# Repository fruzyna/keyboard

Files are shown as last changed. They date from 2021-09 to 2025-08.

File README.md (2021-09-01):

# keyboard

Here I will put my keyboard development. I will attempt to tag each version I get printed. For the first version I used these libraries:
- https://github.com/keebio/keebio-components
- https://github.com/keebio/Keebio-Parts.pretty
- https://github.com/daprice/keyswitches.pretty

I then modded them to my liking for future versions.

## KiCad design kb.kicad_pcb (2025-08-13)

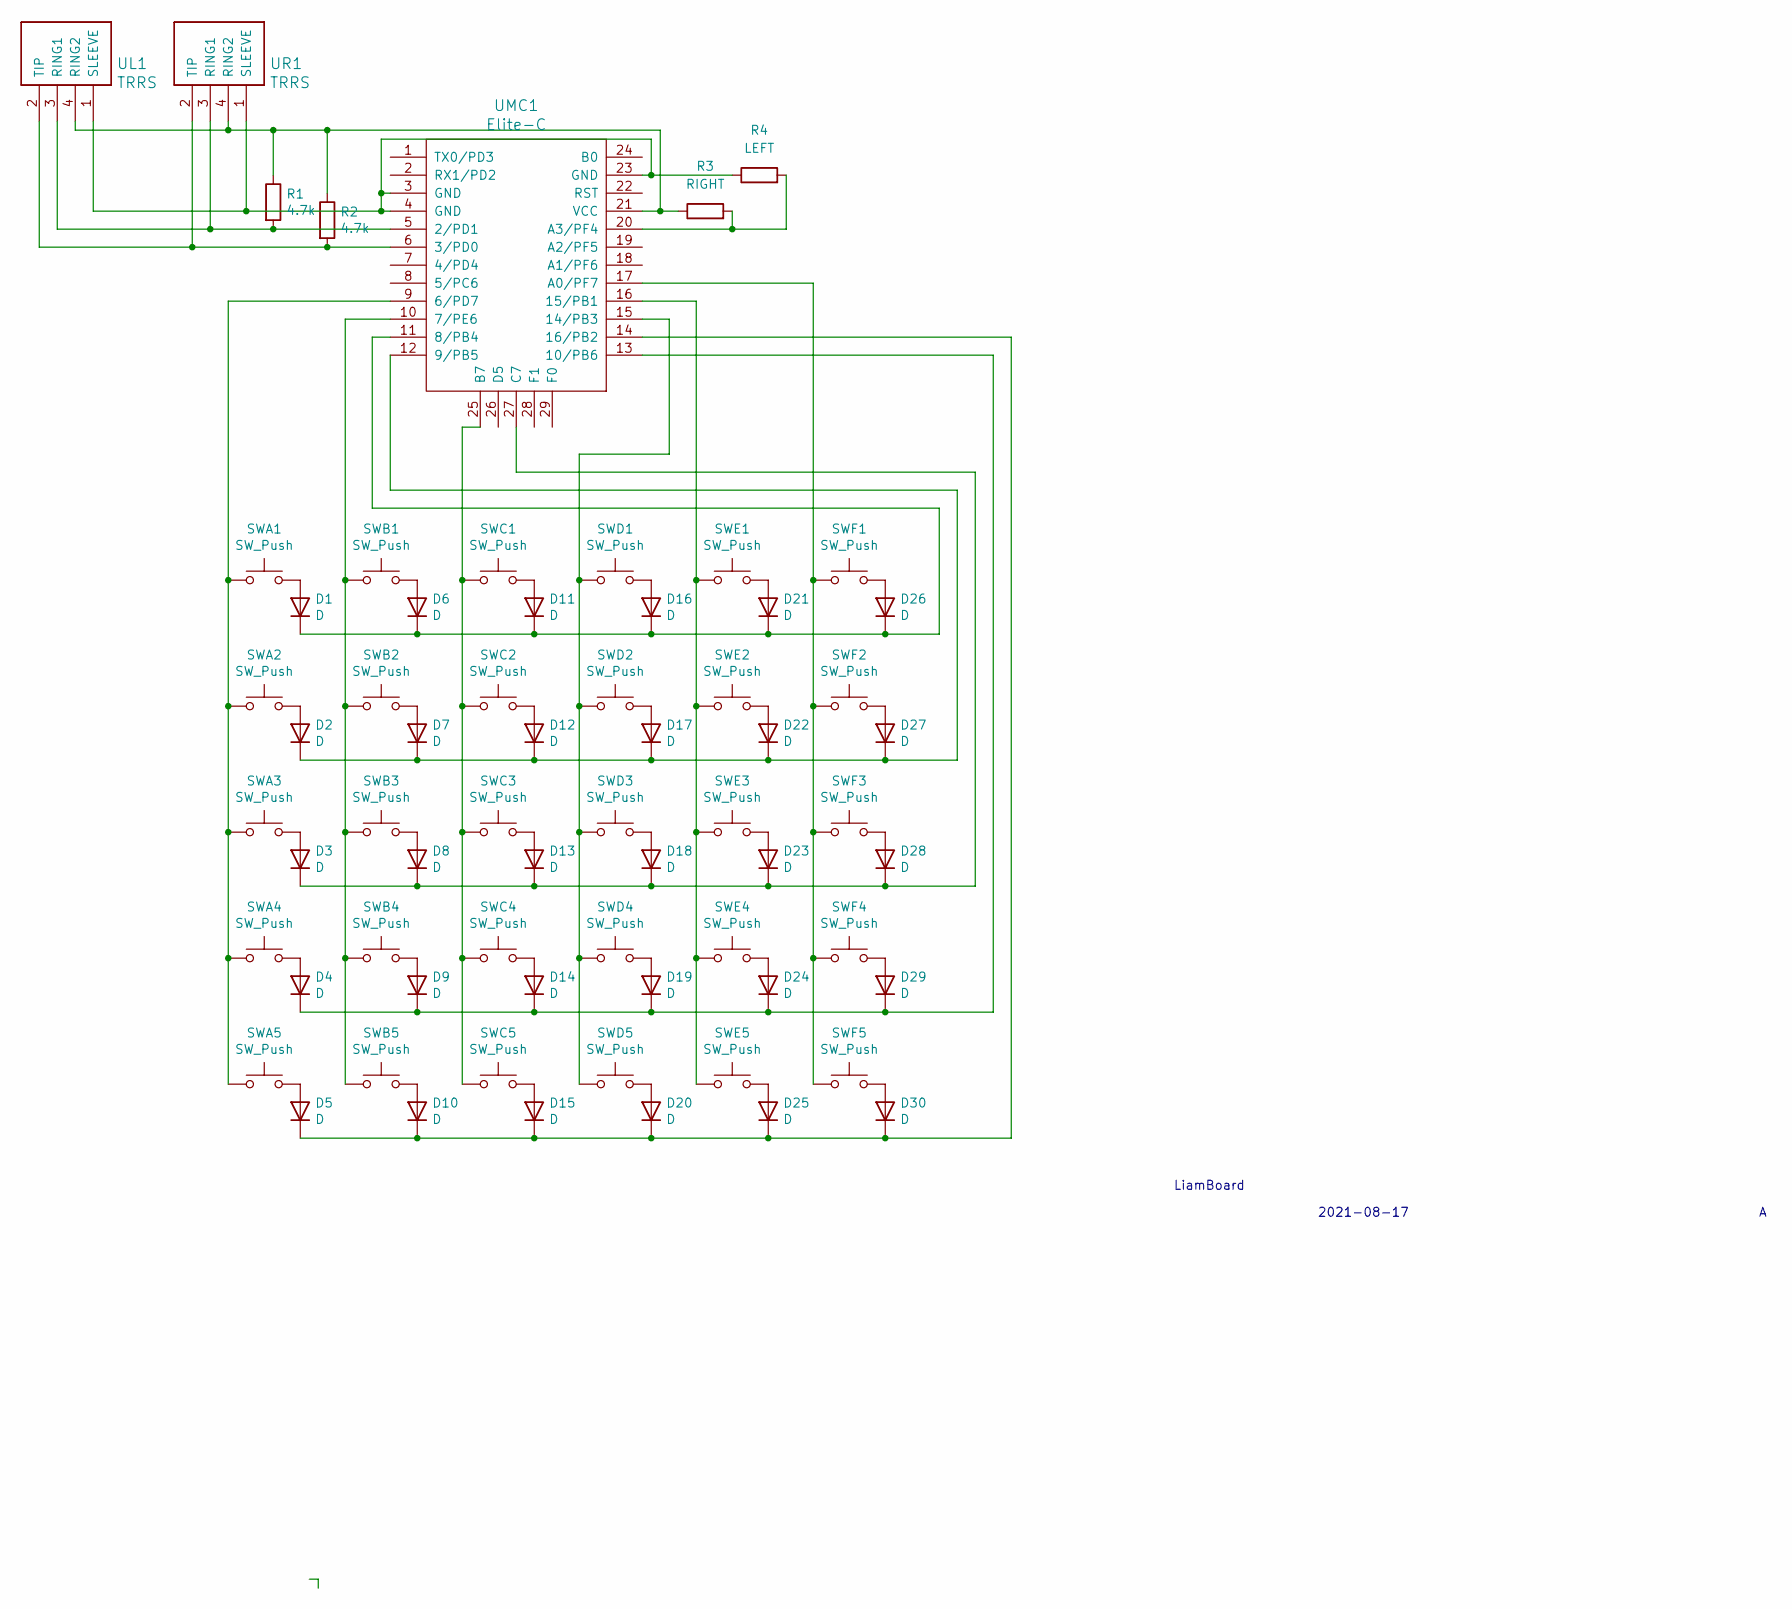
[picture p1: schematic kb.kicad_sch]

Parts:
D1, D2, D3, D4, D5, D6, D7, D8, D9, D10, D11, D12, D13, D14, D15, D16, D17, D18, D19, D20, D21, D22, D23, D24, D25, D26, D27, D28, D29, D30: D; Diode
R1, R2: 4.7k; R_Axial_DIN0207_L6.3mm_D2.5mm_P7.62mm_Horizontal
R3: RIGHT; SolderJumper-2_P1.3mm_Open_TrianglePad1.0x1.5mm
R4: LEFT; SolderJumper-2_P1.3mm_Open_TrianglePad1.0x1.5mm
SWA1, SWA2, SWA3, SWA4, SWA5: SW_Push; SW_MX_reversible
SWB1, SWB2, SWB3, SWB4, SWB5: SW_Push; SW_MX_reversible
SWC1, SWC2, SWC3, SWC4, SWC5: SW_Push; SW_MX_reversible
SWD1, SWD2, SWD3, SWD4, SWD5: SW_Push; SW_MX_reversible
SWE1, SWE2, SWE3, SWE4, SWE5: SW_Push; SW_MX_reversible
SWF1, SWF2, SWF3, SWF4, SWF5: SW_Push; SW_MX_reversible
UL1: TRRS; TRRS-PJ-320A
UMC1: Elite-C
UR1: TRRS; TRRS-PJ-320A

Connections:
unnamed: D1.2 (A), SWA1.2
unnamed: D1.1 (K), D6.1 (K), D11.1 (K), D16.1 (K), D21.1 (K), D26.1 (K), UMC1.11 (8/PB4)
unnamed: D2.2 (A), SWA2.2
unnamed: D3.2 (A), SWA3.2
unnamed: D4.2 (A), SWA4.2
unnamed: D5.2 (A), SWA5.2
unnamed: D6.2 (A), SWB1.2
unnamed: D7.2 (A), SWB2.2
unnamed: D8.2 (A), SWB3.2
unnamed: D9.2 (A), SWB4.2
unnamed: D10.2 (A), SWB5.2
unnamed: D5.1 (K), D10.1 (K), D15.1 (K), D20.1 (K), D25.1 (K), D30.1 (K), UMC1.14 (16/PB2)
unnamed: D11.2 (A), SWC1.2
unnamed: D12.2 (A), SWC2.2
unnamed: D2.1 (K), D7.1 (K), D12.1 (K), D17.1 (K), D22.1 (K), D27.1 (K), UMC1.12 (9/PB5)
unnamed: D13.2 (A), SWC3.2
unnamed: D3.1 (K), D8.1 (K), D13.1 (K), D18.1 (K), D23.1 (K), D28.1 (K), UMC1.27 (C7)
unnamed: D14.2 (A), SWC4.2
unnamed: D4.1 (K), D9.1 (K), D14.1 (K), D19.1 (K), D24.1 (K), D29.1 (K), UMC1.13 (10/PB6)
unnamed: D15.2 (A), SWC5.2
unnamed: D16.2 (A), SWD1.2
unnamed: D17.2 (A), SWD2.2
unnamed: D18.2 (A), SWD3.2
unnamed: D19.2 (A), SWD4.2
unnamed: D20.2 (A), SWD5.2
unnamed: D21.2 (A), SWE1.2
unnamed: D22.2 (A), SWE2.2
unnamed: D23.2 (A), SWE3.2
unnamed: D24.2 (A), SWE4.2
unnamed: D25.2 (A), SWE5.2
unnamed: D26.2 (A), SWF1.2
unnamed: D27.2 (A), SWF2.2
unnamed: D28.2 (A), SWF3.2
unnamed: D29.2 (A), SWF4.2
unnamed: D30.2 (A), SWF5.2
unnamed: R1.2, UL1.3 (RING1), UMC1.5 (2/PD1), UR1.3 (RING1)
unnamed 36: R1.1, R2.1, R3.1, UL1.4 (RING2), UMC1.21 (VCC), UR1.4 (RING2); also elsewhere on the board
unnamed 37: R4.1, UL1.1 (SLEEVE), UMC1.3 (GND), UMC1.4 (GND), UMC1.23 (GND), UR1.1 (SLEEVE); also elsewhere on the board
unnamed: R2.2, UL1.2 (TIP), UMC1.6 (3/PD0), UR1.2 (TIP)
unnamed: SWA1.1, SWA2.1, SWA3.1, SWA4.1, SWA5.1, UMC1.9 (6/PD7)
unnamed: SWB1.1, SWB2.1, SWB3.1, SWB4.1, SWB5.1, UMC1.10 (7/PE6)
unnamed: SWD1.1, SWD2.1, SWD3.1, SWD4.1, SWD5.1, UMC1.15 (14/PB3)
unnamed: SWE1.1, SWE2.1, SWE3.1, SWE4.1, SWE5.1, UMC1.16 (15/PB1)
unnamed: SWF1.1, SWF2.1, SWF3.1, SWF4.1, SWF5.1, UMC1.17 (A0/PF7)
unnamed 44: R3.2, R4.2, UMC1.20 (A3/PF4); also elsewhere on the board
unnamed: SWC1.1, SWC2.1, SWC3.1, SWC4.1, SWC5.1, UMC1.25 (B7)

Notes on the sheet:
2021-08-17
LiamBoard

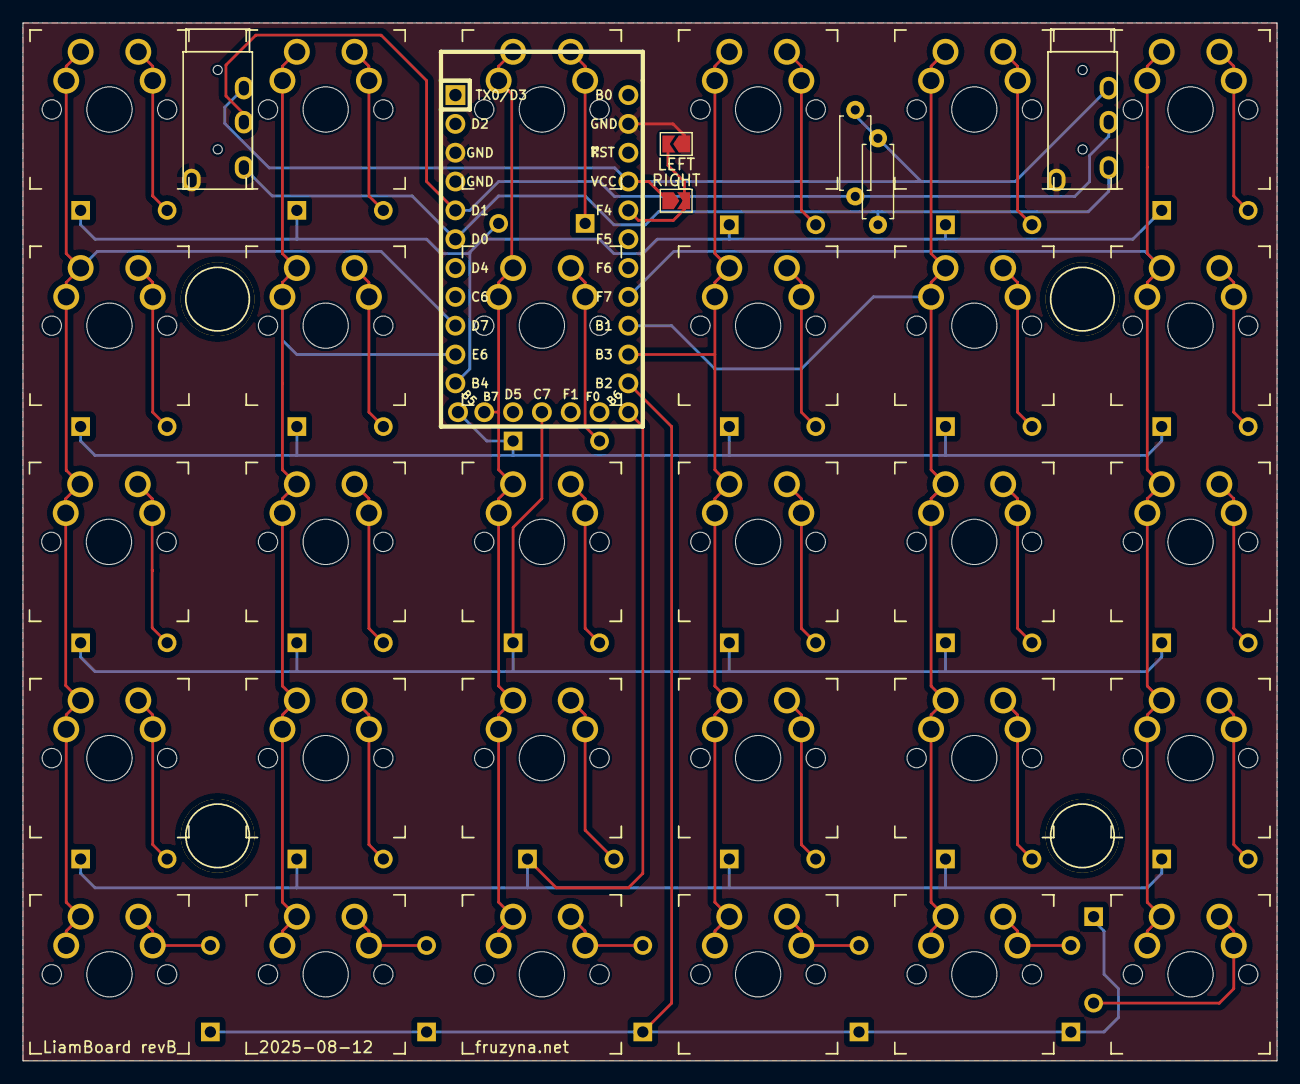
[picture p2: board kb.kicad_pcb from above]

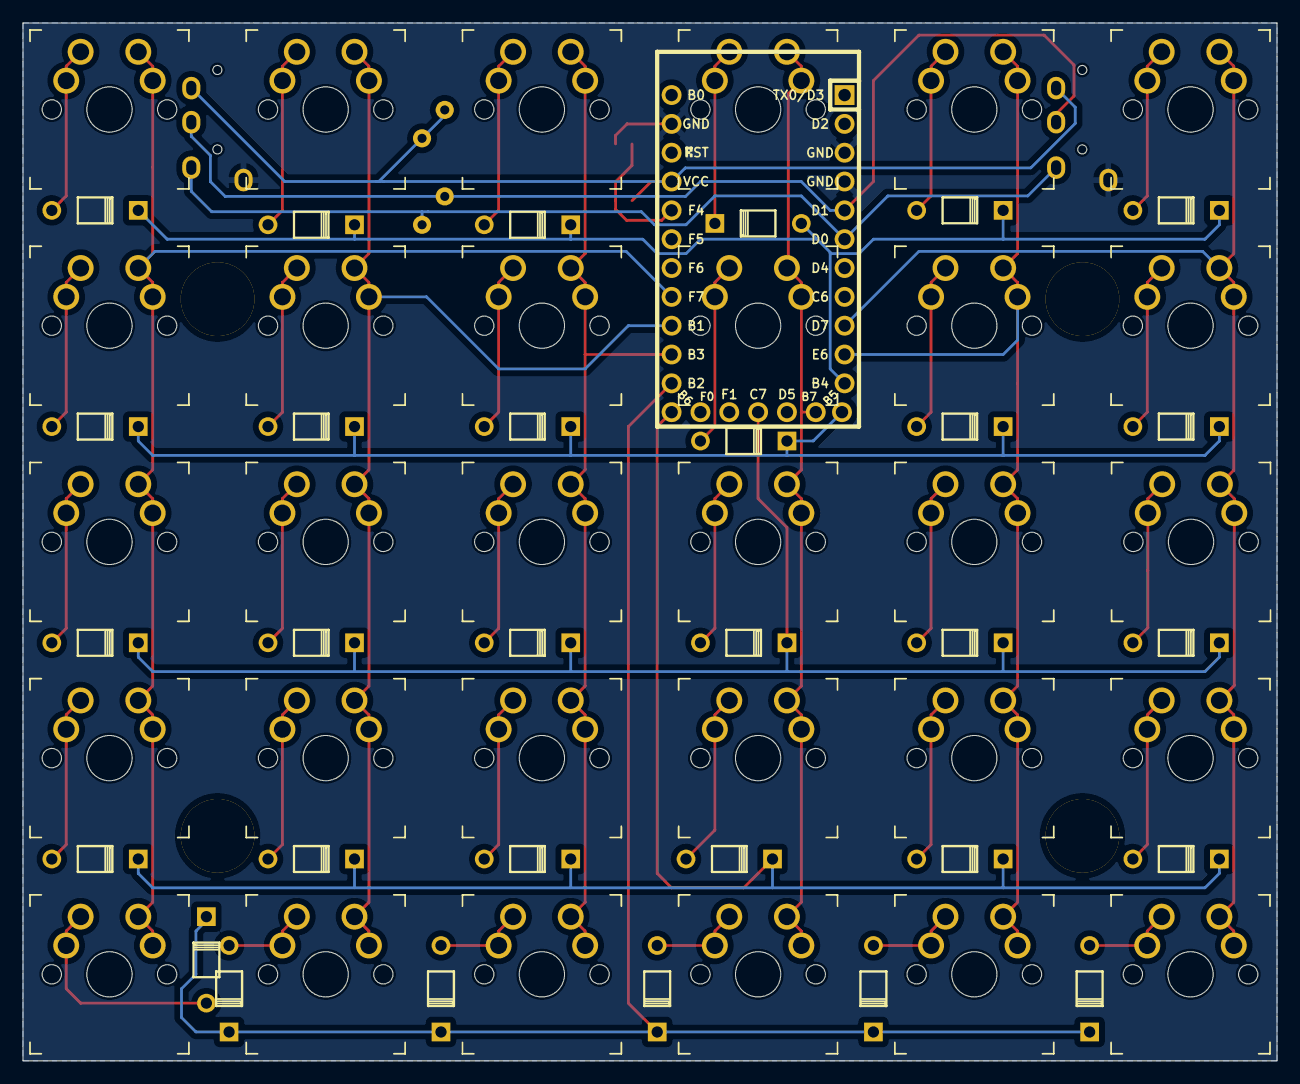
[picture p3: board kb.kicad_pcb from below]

Board: 2 copper layers, 110.5 x 91.4 mm, 71 parts (30 on the bottom side), 46 nets.

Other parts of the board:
LEFT: LEFT; SolderJumper-2_P1.3mm_Open_TrianglePad1.0x1.5mm
RIGHT: RIGHT; SolderJumper-2_P1.3mm_Open_TrianglePad1.0x1.5mm
U4, U4#2, U4#3, U4#4: HOLE; MountingHole

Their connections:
unnamed 36: RIGHT.1; also elsewhere on the board
unnamed 37: LEFT.1; also elsewhere on the board
unnamed 44: LEFT.2, RIGHT.2; also elsewhere on the board

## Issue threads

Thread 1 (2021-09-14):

Diode intersects with trace

fruzyna, 2021-09-14:
Diode D11 intersects the trace connecting digital pin D0 with the left TRRS jack's TIP pin. This can be corrected after the fact by breaking the traces immediately connected with both pin on D11 and manually connecting the diode between switch SWC1 and digital pin B4, but should be corrected in PCB design by shifting D11 down slightly.

Closed 2021-09-15.

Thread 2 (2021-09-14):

Improve fill coverage

fruzyna, 2021-09-14:
There are several large gaps in fill due to ground blockage. One can be fixed by shifting diode D14 slightly to the right. Others can be fixed by strategically connecting the ground planes.

Closed 2021-09-17.

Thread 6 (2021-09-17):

Interboard communication

fruzyna, 2021-09-17:
Board was designed to use I2C but I forgot the resistors to VCC. Serial might just be easier, I planned on supporting varying numbers of board but that may be more complicated than thought.

fruzyna, 2021-09-17:
Also the board doesn't work if only one board is there in I2C mode.

fruzyna, 2021-09-17:
Board is also compatible with serial as is

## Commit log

2021-09-01 My adjusted versions of the footprints
2021-09-15 Fixed intersecting diode and trace (fixed #1)
    [kb.kicad_pcb]
2021-09-15 Shifted diode to improve fill
    [kb.kicad_pcb]
2021-09-17 Improved fill (fixed #2)
    [kb.kicad_pcb]
2021-10-12 Added pull up resistors for I2C
    [kb.kicad_pcb, kb.sch]
2025-07-29 Updated diode footprint to simply be a reverse of the keebio footprint
2025-07-29 Fixed diode orientation (#3), added bridge points for left/right board, and other cleanup
    [kb.kicad_pcb, kb.kicad_sch]
2025-08-13 Silkscreen tweaks
    [kb.kicad_pcb]
